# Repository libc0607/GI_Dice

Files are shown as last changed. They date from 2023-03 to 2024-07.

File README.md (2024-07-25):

本项目已停止更新，已停止任何形式的技术支持。但您仍然可以查看全部开源资料，并在遵守开源协议的情况下使用。  
如果您遇到任何问题，可以学习那位的美德后自行解决，也可以在教令院找阿帽。阿帽不好听吗？  

---

# GI Dice
这是一种原神七圣召唤中的元素骰子的可低成本 DIY 的实现  
本设计中，除了外壳、元素图标及 PCB 需要给 JLC 氪点之外，其余全部使用立创商城或淘宝零售可买到的全新部件实现，无需额外定制  
关于使用效果，你可以看看 [BV1Gs4y1t7k7](https://www.bilibili.com/video/BV1Gs4y1t7k7)  
  

## 特性
 - CH573F 主控，通过蓝牙广播实现多个骰子同时向中控传输骰子朝向及电量信息
 - 打牌计分中控我没打算做，但给出了在 ESP32-S3 上做接收的例程，想做中控的可以直接对接
 - LIS2DW12 三轴加速度传感器
 - 8 个 APA102 (SK9822) RGB LED，支持关断 LED 电源以省电（*见下文续航）
 - LIR1240 55mAh 锂电池，以及正经的充电管理和电池保护 IC
 - 使用无线充电，同样开源了配套的充电盒
 - 霍尔传感器实现放入充电盒后关断电源
 - 正八面体，边长 22mm

续航与电池电压、温度、元件及使用场景等多种因素有关，没有全面地测量过，这里只给出我的一次测量的结果用于粗略估计  
|  工作状态 | 电池的输出电流  |
|  ----  | ----  |
| 正常工作，蓝牙广播，1灯亮  | ~7.5mA |
| 正常工作，蓝牙配对，1灯亮  | ~9.5mA |
| 正常工作，蓝牙广播，灯灭  | ~2.5mA |
| 正常工作，蓝牙配对，灯灭  | ~4.5mA |
| 十分钟（默认）无动作后休眠  | ~数十uA |
| 放入充电盒盖上盖子  | ~8uA |

## TO-DOs 
写完各个 README 

## 开源协议  
本仓库内全部的 原理图、PCB、外壳，适用于 CERN-OHL-S v2 或任何之后的版本  
其中，霍尔开关和无线充电的部分设计有参考 [jeansimonet/Pixels](https://github.com/jeansimonet/Pixels) 项目，该项目基于 MIT 协议开源  
  
dice/src 下包含的软件中，我自己写的部分基于 GPL v3 开源（反正加一起也没写几行还写得那么烂不会真的有人想在这上面改吧x   
其他需要作出声明的包括：
 - lis2dw12 驱动来自 [STMicroelectronics/lis2dw12-pid](https://github.com/STMicroelectronics/lis2dw12-pid)，原代码基于 BSD 3-Clause 协议开源
 - 代码主体修改自 [CH573EVT](https://www.wch.cn/downloads/CH573EVT_ZIP.html) 的 BLE_UART 示例，原代码基于 Apache-2.0 协议开源  
 - esp32_dice_scanner 修改于 [espressif/arduino-esp32](https://github.com/espressif/arduino-esp32) 中提供的 BLE_Beacon_Scanner 示例，由于基于 LGPL-2.1 开源，这部分就跟着用相同的   

作者不对 dice/panel 目录下带有元素图标的面板打印文件声明任何协议，作者也没有把这个文件商用，总之就是先放这    
其中图纸来自 [B站 @芒果小强DY：教你如何实现元素骰子自由](https://www.bilibili.com/video/BV1S14y1K7hi)，但其中的美术素材（元素 Logo）版权归属于自由的 mhy  
如果认为这部分有侵权的话，请联系删除  

禁止拿去做毕设，你也不想被你的答辩老师知道你平日其实都在原神里打牌吧（

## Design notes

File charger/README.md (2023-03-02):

# 元素骰子用的无线充电器 
在 [这个视频](https://www.bilibili.com/video/BV1Gs4y1t7k7/) 中出现的充电器  
  
使用 XKT-511 方案，主要参考了 XKT511-21 这个验证板  
实测谐振频率 ~940kHz，接收侧使用 10uH 并联 2.2nF 即可  
在双路充电基础上增加了一个 CH552，用于检测充电电流、充电器内部温度和充电器的盖子状态   
不过这些功能的代码还全都没写，你可以先写两行把 XKT-511 的使能拉高，先用着。。  

硬件：双层板，板厚 1.6mm，白嫖即可，无特殊工艺要求  
除了两个 10nF 的谐振电容需要使用 C0G/NP0 材质外，其余均可参考原理图中元件型号  
建议用黑油，因为画得太丑了（悲  
  
配套的外壳见 stl/  
OSHWHub 的 PCB 工程链接：https://oshwhub.com/libc0607/gi_dice_charger_dual_nobat_v1_0_rel

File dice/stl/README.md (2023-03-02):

# 外壳
[一图流组装指南](https://github.com/libc0607/GI_Dice/blob/main/dice/stl/Schematic_gi_dice_doc_2023-03-02.pdf)

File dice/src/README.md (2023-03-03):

# BLE_Dice demo 

与 CH573EVT V2.2 版本一同测试通过  
代码参考了 CH573EVT V2.2 中的 BLE_UART Demo  
下文截图使用了沁恒的 BLE 调试助手 APP  

## 使用 BLE 和打牌中控进行交互  
如果你正试图实现打牌中控，那么目前支持通过两种方式经 BLE 获取骰子的状态信息，分别为监听广播包（一对多）和配对后（一对一）  


### 从广播包中获取信息   
  

| 长度 | 类型 | 数据 | 数据在 advert/scan_rsp 包中 | 备注 |
|---|---|---|---|---|
| 2 | GAP_ADTYPE_FLAGS | DEFAULT_DISCOVERABLE_MODE \| GAP_ADTYPE_FLAGS_BREDR_NOT_SUPPORTED | advert | 默认 | 
| 3 | GAP_ADTYPE_16BIT_MORE | 16bit 短 Service UUID，fff0 | advert | 修改自 BLE_UART，默认 |
| 5 | GAP_ADTYPE_MANUFACTURER_SPECIFIC | “制造商数据”：'G'(0x47), 'I'(0x49), (uint8)((电池电压mV-3200)/4), ([lis_dice_8d_t](https://github.com/libc0607/GI_Dice/blob/a4a67a805def9365946631231ff4620e6b9b3964/dice/src/BLE_Dice/APP/include/lis2dw12_glue.h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))朝向 | advert | 只解析这个即可 |
| 9 | GAP_ADTYPE_LOCAL_NAME_COMPLETE | 骰子显示的名称：Dice8AA1，前4固定，后4字节是MAC地址末尾且大写 | scan_rsp | 可用于判定&配对检查 | 
  
### BLE 配对后进行交互 
这部分本质上是直接使用了 BLE_UART 示例中提供的虚拟串口来发送与接收数据   
Service UUID 为 0xfff0  
  

Characteristic 0xfff1 为 骰子->中控，接收骰子发来的数据时，打开 Notify，然后接收就行   
数据格式为：
'#'，电池电压mV，温度（但是好像Bug了），([lis_dice_8d_t](https://github.com/libc0607/GI_Dice/blob/a4a67a805def9365946631231ff4620e6b9b3964/dice/src/BLE_Dice/APP/include/lis2dw12_glue.h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))朝向，加速度[0]，加速度[1]，加速度[2]  
其中加速度范围为 [-2000, 2000]，单位为 mg  
   

Characteristic 0xfff2 为 中控->骰子，这坨代码目前只能接收一种数据，即在接收到字符 'F' 后点亮全部 LED 约一秒，用于实现初次与中控配对时在一堆骰子里找到对应的骰子  


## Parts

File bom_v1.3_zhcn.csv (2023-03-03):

 |  | 部件 | 规格 | 数量 | 备注
骰子本体 电路部分 | PCB | GI_Dice_V1.3_Rel |  | 1 | JLC白嫖，https://oshwhub.com/libc0607/gi_dice_v1-3_rel
 | 元件 建议SMT | 100nF | C0402 | 6
 |  | 2.2uF | C0402 | 4
 |  | 10nF | C0402 | 2
 |  | 1uF | C0402 | 2 | 耐压25V或以上
 |  | 10uF | C0402 | 2
 |  | 100kΩ | R0402 | 2
 |  | 1MΩ | R0402 | 2
 |  | 1kΩ | R0402 | 1
 |  | 3.3kΩ | R0402 | 1
 |  | LIS2DW12TR | LGA-12_L2.0-W2.0-P0.50-BL | 1
 |  | LGS4056H | DFN-8_L2.0-W2.0-P0.50-BL-EP-1 | 1 | 有 4.2V 和 4.35V 版本，根据你的电池选择，通常选 4.2V
 |  | CM1124-EAC | DFN-4_L1.0-W1.0-P0.65-BL-EP-A | 1 | 有 4.2V 和 4.35V 版本，根据你的电池选择，通常选 4.2V
 | 元件 可以手焊 | CA-C01 2.4G天线 |  | 1 | https://item.taobao.com/item.htm?id=627328734225
 |  | 2.2nF | C0402 | 1 | 要 NP0/C0G 材质，耐压25V或以上，如 https://item.szlcsc.com/3443038.html
 |  | BAV99S | SOT-363_L2.1-W1.3-P0.65-LS2.3-BL | 1
 |  | 22uH | IND-SMD_L2.0-W1.6_NR201610 | 1 | 具体参考 CH573 手册，我实际用了个 10uH 0.4A 0603 功率电感 https://detail.tmall.com/item.htm?id=614042556481
 |  | APA102-2020 | APA102-2020 | 8 | https://item.taobao.com/item.htm?id=593679077814
 |  | TJ-S1615SW6TGLCRG-A5 | LED-ARRAY-SMD_4P-L1.6-W1.5-TR-RD_TJ-S1615SW6TGLCRB-A5 | 1 | 例如优信 https://item.taobao.com/item.htm?id=522572822666
 |  | CJE3139K | SC-75-3_L1.6-W0.8-P1.00-LS1.7-BR | 1
 |  | CH573F | QFN-28_L4.0-W4.0-P0.40-BL-EP2.8 | 1
 |  | SGM2036-3.3YC5G/TR | SC-70-5_L2.1-W1.3-P0.65-LS2.1-BR | 1
 |  | 8P FPC 排线 | 8P 0.8MM间距 30MM长 | 1 | https://item.taobao.com/item.htm?id=639292801110
 |  | 3P FPC 排线 | 3P 1.0MM间距 30MM长 | 1 | https://item.taobao.com/item.htm?id=639292801110
 |  | 74LVC1G00DCKR | SC-70-5_L2.0-W1.3-P0.65-LS2.1-BR | 1
 |  | HT7150S | SOT-23-3_L2.9-W1.5-P1.90-LS2.8-BR-CW | 1 | 可换，但注意输入耐压要高于25V
 |  | 32MHz | CRYSTAL-SMD_4P-L2.0-W1.6-BL-2 | 1
 |  | 32.768k | CRYSTAL-SMD_L2.1-W1.2-P1.50 | 0 | 仅预留，不用焊
 |  | CC6203ST? | SOT-23-3 | 1 | 也可换其他相似型号，https://item.szlcsc.com/271303.html
 |  | 10uH 电感 | CD53 | 2 | 磁路必须不能闭合，买最便宜的就对了；必须CD53，厚了塞不进去
 |  | 飞线 |  | 若干 | 可以买那种耳机用的线材，细一些
 |  | LIR1240 锂电池 | Φ 12mm*4mm | 1 | 淘宝很好买，如果担心盖不上，换薄一些的 301012 电池
骰子 结构组装 |  | 青稞纸 | 不要太厚的 | 若干 | 自己剪
 |  | 隔磁片 | 不要太厚的 | 若干 | 建议在给充电器买 XKT-511 时顺便一起买了
 |  | 双面胶 | 不要太厚的 | 若干
 |  | 10号订书钉 |  | 4 | 用于固定上下壳
 |  | 元素图标面板 | 透明亚克力/正面/0.8mm/常规遮光 | 8种元素，一套共8片 | 立创面板打印 https://github.com/libc0607/GI_Dice/blob/main/dice/panel/Panel_GI_Dice_Panel_Demo_2023-01-03.epanm
 |  | 外壳 | 光固化3D打印 | 2 | https://github.com/libc0607/GI_Dice/blob/main/dice/stl/dice_main_v1.3.STL
 |  | 金色喷漆 |  |  | 我用的三和35#，你可以选择更好的
 |  | 光油 |  |  | 我用的三和190#，你可以选择更好的
 |  | 磁铁 | Φ2mm * 1.5mm | 4（可选） | 用作上下壳间的定位柱，可选
 |  | 砂纸 |  | 若干
充电器 电路部分 |  | GI_Dice_Charger_V1.0_Rel |  | 1 | 可白嫖，https://oshwhub.com/libc0607/gi_dice_charger_dual_nobat_v1_0_rel
 |  | 10KΩ(1002) | R0603 | 1 | 热敏电阻，B3380
 |  | 5.1K | R0603 | 9
 |  | CC6201TO | TO-92S_3P-L4.1-W1.6-P1.27-L | 1 | https://item.szlcsc.com/271302.html
 |  | 10nF | C0603 | 2 | 要 NP0/C0G 材质，耐压不能太低，如 https://item.szlcsc.com/87149.html
 |  | 100nF | C0603 | 4
 |  | 22uF | C0805 | 2
 |  | Red | LED0603-R-RD | 1
 |  | Green | LED0603-R-RD | 1
 |  | 200kΩ | R0603 | 2
 |  | 11kΩ | R0603 | 2
 |  | 1MΩ | R0603 | 4
 |  | 100mΩ | R0805 | 2
 |  | XKT-511 | XKT-511 | 2 | https://item.taobao.com/item.htm?id=620604429073
 |  | CH552G | SOP-16_L10.0-W3.9-P1.27-LS6.0-BL | 1
 |  | SGM8522XS/TR | SOIC-8_L4.9-W3.9-P1.27-LS6.0-BL | 1 | 注意静电
 |  | TYPE-C-31-M-12 | USB-C_SMD-TYPE-C-31-M-12 | 1
充电器 外壳 |  | 外壳-本体 | 光固化3D打印 | 1 | https://github.com/libc0607/GI_Dice/blob/main/charger/stl/dualchrg-v1.0.STL
 |  | 外壳-底盖 | 光固化3D打印 | 1 | https://github.com/libc0607/GI_Dice/blob/main/charger/stl/dualchrg-bottom_v1.0.STL
 |  | 外壳-顶盖 | 光固化3D打印 | 1 | https://github.com/libc0607/GI_Dice/blob/main/charger/stl/dualchrg-cap_v1.2.STL
 |  | 磁铁 | Φ6mm * 0.5mm | 8 | 上下盖子磁吸用
 |  | 磁铁 | Φ8mm * 1.0mm | 2 | 关断骰子电源用
 |  | 磁铁 | Φ2mm * 1.5mm | 1 | 给合盖霍尔传感器用；上述所有磁铁可在同一店买到（*lalaci）
 |  | 砂纸 |  | 若干

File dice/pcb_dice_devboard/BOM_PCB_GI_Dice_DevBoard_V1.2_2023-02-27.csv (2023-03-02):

ID | Name | Designator | Footprint | Quantity | Manufacturer Part | Manufacturer | Supplier | Supplier Part | Price
1 | C23630 | C4 | C0603 | 1 | C2980295 | SAMSUNG(三星) | LCSC | C23630 | 0.0336
2 | 100nF | C2,C8,C12,C13 | C0603 | 4 | CC0603KRX7R9BB104 | YAGEO(国巨) | LCSC | C14663 | 0.0149
3 | 2.2uF | C3,C5,C6,C7,C14,C15 | C0603 | 6 | CL10A225KO8NNNC | SAMSUNG(三星) | LCSC | C23630 | 0.0336
4 | C23630 | C1 | C0603 | 1 | CC0603KRX7R9BB104 | YAGEO(国巨) | LCSC | C14663 | 0.0149
5 | 10uF | C10,C11 | C0603 | 2 | CL10A106KP8NNNC | SAMSUNG(三星) | LCSC | C19702 | 0.0417
6 | 2.2nF | C9 | C0402 | 1 | 0402B222K500NT | FH(风华) | LCSC | C1531 | 0.0063
7 | BAV99S | D2 | SOT-363_L2.1-W1.3-P0.65-LS2.3-BL | 1 | BAV99S | CJ(江苏长电/长晶) | LCSC | C68987 | 0.3179
8 | Z-211-0511-0021-001 | H1 | HDR-TH_5P-P2.54-V_Z-211-0511-0021-001 | 1 | Z-21105110021001 | Nextron(正凌) | LCSC | C188243 | 0.1983
9 | 22uH | L1 | IND-SMD_L2.0-W1.6_NR201610 | 1 | YNR2016-220M | YJYCOIN(益嘉源) | LCSC | C2858408 | 0.3743
10 | OA-C07 | L4 | OA-C07 | 1
11 | APA102-2020 | LED1,LED2,LED3,LED4,LED5,LED6,LED7,LED9 | APA102-2020-COPY | 8 | APA102-2020 |  | LCSC | C9900001305
12 | 19-217/GHC-YR1S2/3T | LED8 | LED0603-R-RD | 1 | 19-217/GHC-YR1S2/3T | EVERLIGHT(亿光) | LCSC | C72043 | 0.1678
13 | KT-0603R | LED10 | LED0603-R-RD | 1 | KT-0603R | null | LCSC | C2286 | 0.0332
14 | 100kΩ | R1 | R0603 | 1 | 0603WAF1003T5E | UNI-ROYAL(厚声) | LCSC | C25803 | 0.0068
15 | 1MΩ | R2,R5 | R0603 | 2 | 0603WAF1004T5E | UNI-ROYAL(厚声) | LCSC | C22935 | 0.0059
16 | 15kΩ | R3,R4,R6 | R0603 | 3 | 0603WAF1502T5E | UNI-ROYAL(厚声) | LCSC | C22809 | 0.0065
17 | 5.1kΩ | R7,R8 | R0603 | 2 | 0603WAF5101T5E | UNI-ROYAL(厚声) | LCSC | C23186 | 0.0061
18 | TS-1088-AR02016 | SW1 | SW-SMD_L3.9-W3.0-P4.45 | 1 | TS-1088-AR02016 | XUNPU(讯普) | LCSC | C720477 | 0.2947
19 | LIS2DW12TR | U1 | LGA-12_L2.0-W2.0-P0.50-BL | 1 | LIS2DW12TR | ST(意法半导体) | LCSC | C189624 | 5.28
20 | CH582F | U2 | QFN-28_L4.0-W4.0-P0.40-BL-EP2.8 | 1 | CH582F | WCH(南京沁恒) | LCSC | C3001175 | 6.79
21 | LP5907MFX-3.3/NOPB | U3 | SOT-23-5_L3.0-W1.7-P0.95-LS2.8-BR | 1 | LP5907MFX-3.3/NOPB | TI(德州仪器) | LCSC | C80670 | 1.676
22 | SY6280AAC | U4 | SOT-23-5_L3.0-W1.7-P0.95-LS2.8-BR | 1 | SY6280AAC | 矽力杰silergy | LCSC | C55136 | 1.0866
23 | TP4057 | U6 | SOT-23-6_L2.9-W1.6-P0.95-LS2.8-BR | 1 | TP4057-42-SOT26-R | TOPPOWER(南京拓微) | LCSC | C12044 | 0.8511
24 | CC6201ST | U7 | SOT-23-3_L2.9-W1.3-P1.90-LS2.4-BR | 1 | CC6201ST | CrossChip(成都芯进) | LCSC | C285995 | 0.6216
25 | 74LVC1G08 | U10 | SC-70-5_L2.0-W1.3-P0.65-LS2.1-BR | 1 | SN74LVC1G08DCKR | UMW(友台半导体) | LCSC | C2983745 | 0.3563
26 | HT7550S | U11 | SOT-23-3_L2.9-W1.5-P1.90-LS2.8-BR-CW | 1 | HT7550S | UMW(友台半导体) | LCSC | C347217 | 0.3053
27 | TYPE-C-31-M-12 | USBC2 | USB-C_SMD-TYPE-C-31-M-12 | 1 | TYPE-C-31-M-12 | Rectangular Connectors - Contacts | LCSC | C165948 | 1.3658
28 | 32MHz | X1 | CRYSTAL-SMD_4P-L2.0-W1.6-BL-2 | 1 | X201632MOB4SI | YXC(扬兴晶振) | LCSC | C2682773 | 0.6645
29 | 32.768k | X2 | CRYSTAL-SMD_L2.1-W1.2-P1.50 | 1 | TJXM32768K2TGDCNT2T | TAE(Zhejiang Abel Elec) | LCSC | C403709 | 1.637
30 | 22-28-4020 | CN1,CN2 | HDR-TH_2P-P2.54-V-M-1 | 2 | 22284020 | MOLEX | LCSC | C234182 | 0.5255

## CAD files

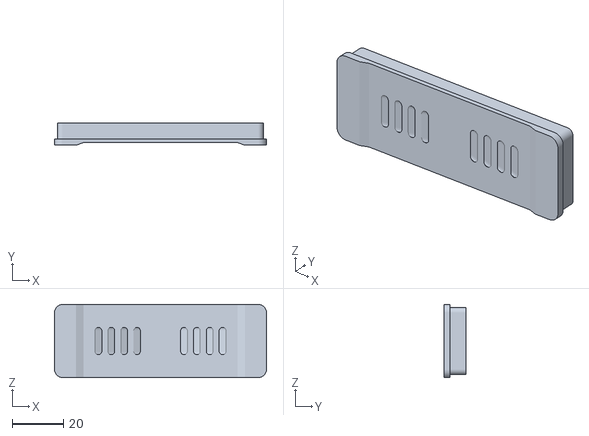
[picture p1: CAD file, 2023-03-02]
charger/stl/dualchrg-bottom_v1.0.STL
82.4 x 8.70 x 28.4

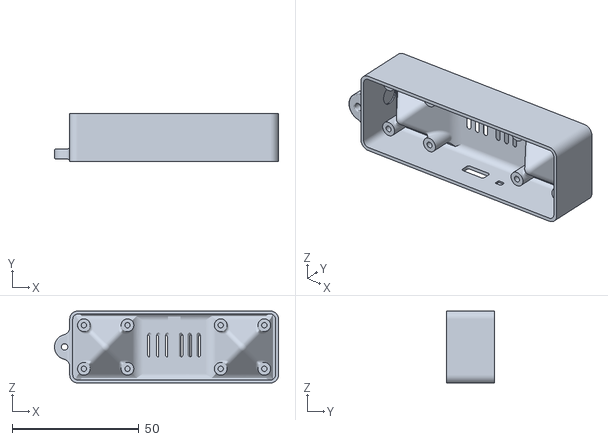
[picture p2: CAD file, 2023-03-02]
charger/stl/dualchrg-v1.0.STL
88.4 x 19.0 x 28.4

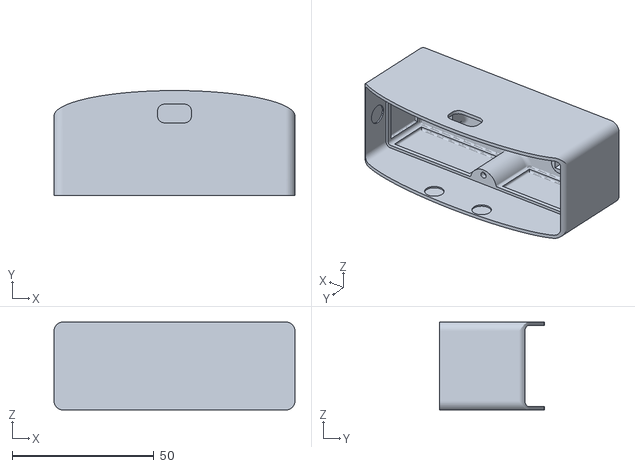
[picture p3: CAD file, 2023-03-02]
charger/stl/dualchrg-cap_v1.2.STL
85.0 x 37.0 x 31.0

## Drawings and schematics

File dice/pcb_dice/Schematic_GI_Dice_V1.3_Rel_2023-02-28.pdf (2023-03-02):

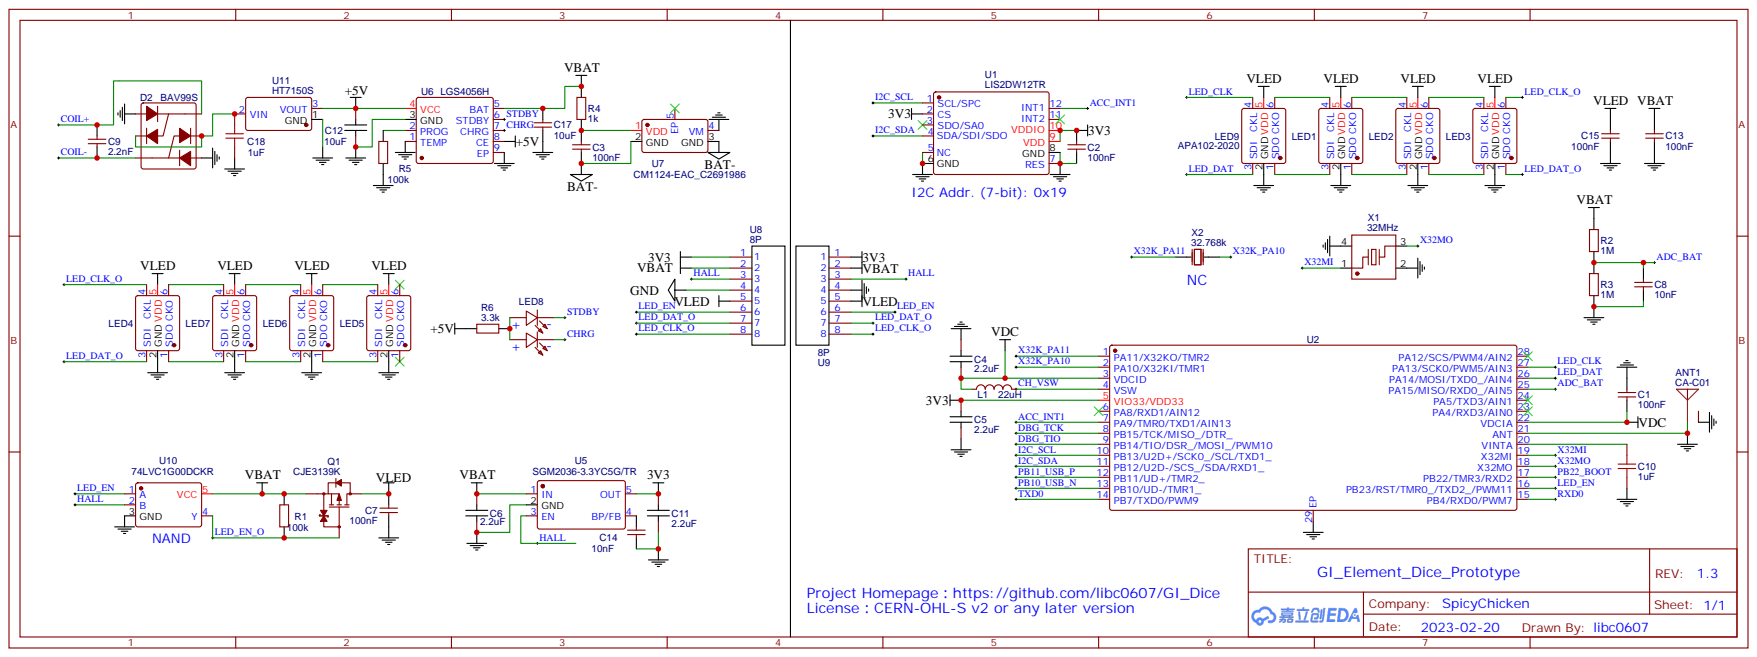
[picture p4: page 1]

Project Homepage：https://github.com/libc0607/GI_Dice
License：CERN-OHL-S v2 or any later version

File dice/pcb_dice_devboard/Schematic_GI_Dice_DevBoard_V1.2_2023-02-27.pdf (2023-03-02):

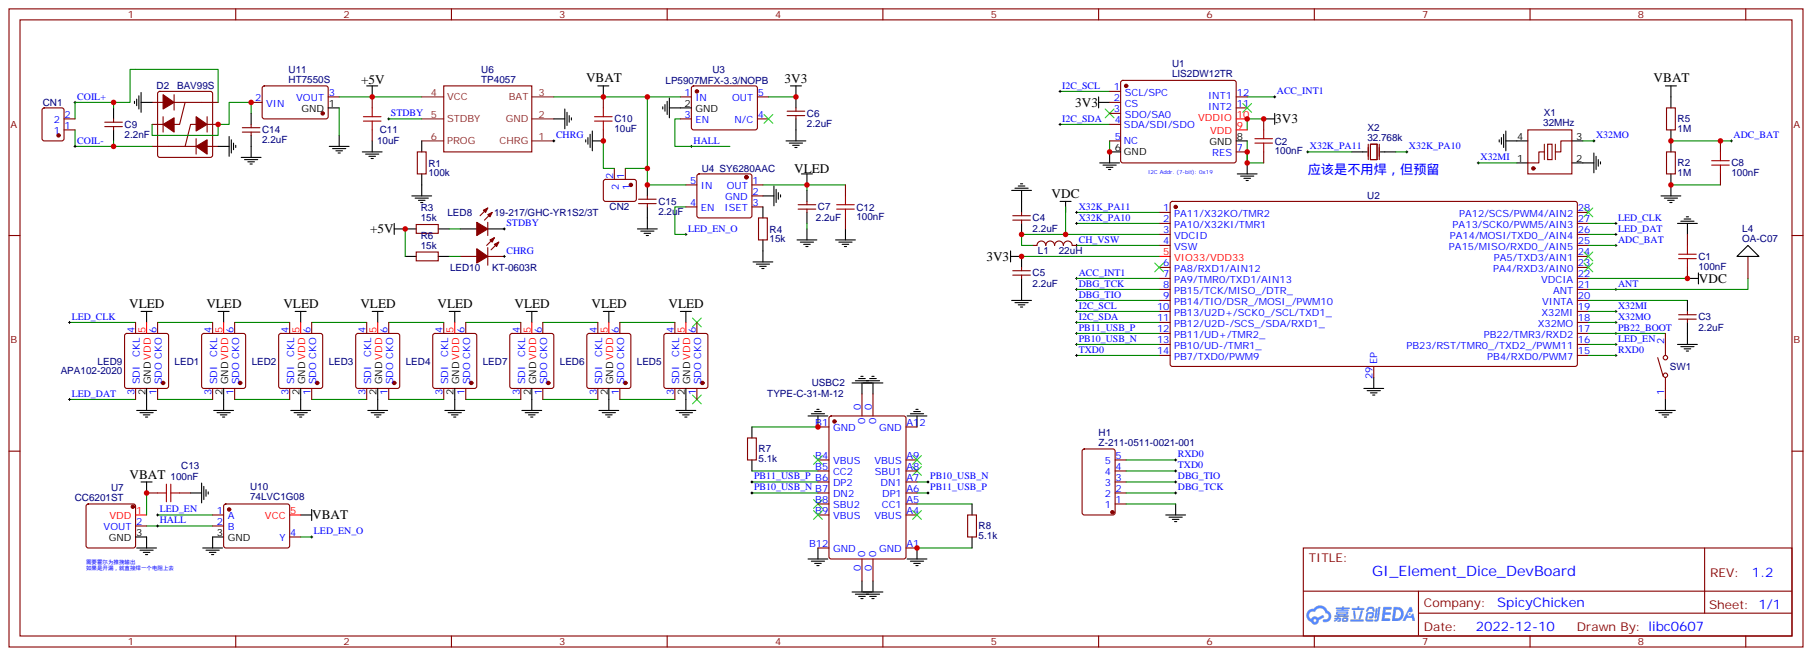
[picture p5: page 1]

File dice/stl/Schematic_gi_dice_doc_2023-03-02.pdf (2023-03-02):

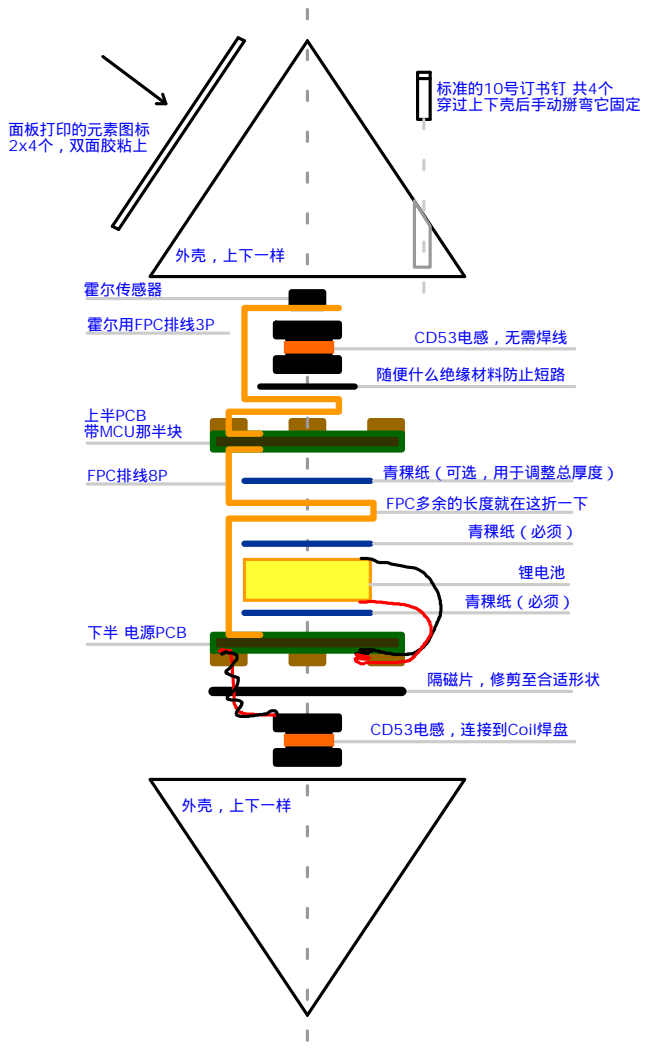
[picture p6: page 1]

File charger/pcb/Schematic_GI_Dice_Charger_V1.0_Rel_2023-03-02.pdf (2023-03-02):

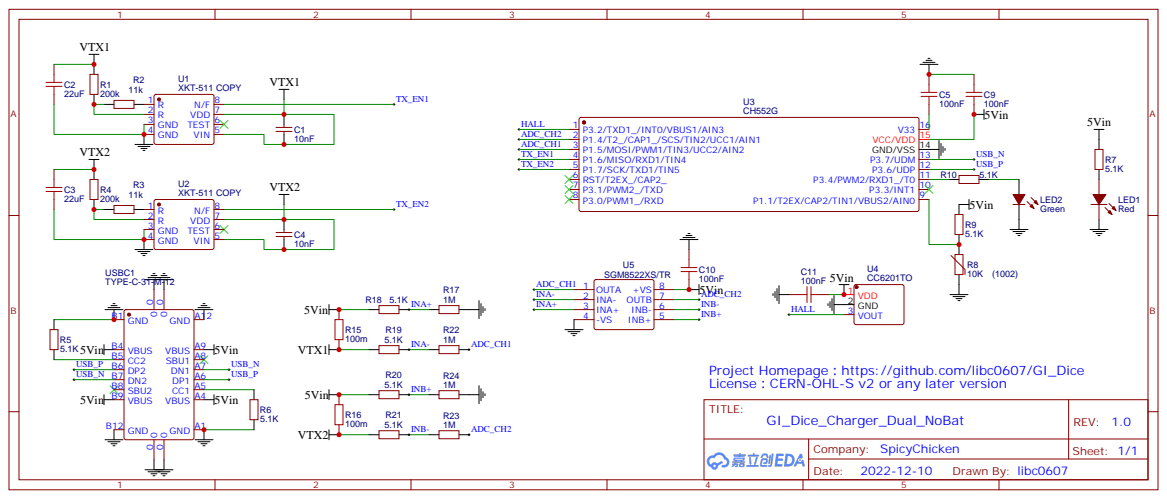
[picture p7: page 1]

Project Homepage：https://github.com/libc0607/GI_Dice
License：CERN-OHL-S v2 or any later version

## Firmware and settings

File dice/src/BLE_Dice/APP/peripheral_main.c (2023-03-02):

/*
 * Genshin Impact Genius Invokation Element Dice
 *
 * HW Version: V1.2
 * Github: https://github.com/libc0607/GI_Dice
 *
 * Ref: CH573EVT V2.2, BLE_UART demo
 */

#include "CONFIG.h"
#include "HAL.h"
#include "gattprofile.h"
#include "peripheral.h"
#include "dice_misc.h"
#include "lis2dw12_glue.h"
#include "apa102.h"

__attribute__((aligned(4))) u32 MEM_BUF[BLE_MEMHEAP_SIZE / 4];
extern void app_uart_init(void);

__attribute__((section(".highcode")))
__attribute__((noinline))
void Main_Circulation()
{
    while(1)
        TMOS_SystemProcess();
}

/*
__attribute__((interrupt("WCH-Interrupt-fast")))
__attribute__((section(".highcode")))
void GPIOA_IRQHandler(void)
{
    GPIOA_ClearITFlagBit(PIN_ACC_INT);
}
*/

int main(void)
{
    int bat_mv;
    uint32_t color_bat;

    PWR_DCDCCfg(ENABLE);
    SetSysClock(FREQ_SOURCE);

    pin_init();
    UART0_DefInit();
    PRINT("%s\n", VER_LIB);
    acc_init();
    apa102_spi0_init();
    apa102_power_enable(TRUE);

    // blinky battery indicator
    bat_mv = get_battery_voltage_mv();
    color_bat = get_led_color_by_battery(bat_mv);
    apa102_turn_off_all(); apa102_set_color_all(LED_STAT_BRIGHTNESS_DEFAULT, color_bat); apa102_update(); DelayMs(BOOT_BLINK_INTERVAL);
    apa102_turn_off_all(); apa102_update(); DelayMs(BOOT_BLINK_INTERVAL);
    apa102_turn_off_all(); apa102_set_color_all(LED_STAT_BRIGHTNESS_DEFAULT, color_bat); apa102_update(); DelayMs(BOOT_BLINK_INTERVAL);
    apa102_turn_off_all(); apa102_update(); DelayMs(BOOT_BLINK_INTERVAL);
    apa102_turn_off_all(); apa102_set_color_all(LED_STAT_BRIGHTNESS_DEFAULT, color_bat); apa102_update(); DelayMs(BOOT_BLINK_INTERVAL);
    apa102_turn_off_all(); apa102_update();
    apa102_power_enable(FALSE);

    if (bat_mv < BAT_HALT_MV) {
        acc_low_power();
        DelayMs(1);
        pin_init_sleep();
        DelayMs(2);
        LowPower_Shutdown(0);
    }

    CH57X_BLEInit();
    HAL_Init();
    GAPRole_PeripheralInit();
    Peripheral_Init();
    app_uart_init();
    dice_process_init();

    Main_Circulation();
}

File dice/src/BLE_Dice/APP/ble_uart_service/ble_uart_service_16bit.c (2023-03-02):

/********************************** (C) COPYRIGHT *******************************
 * File Name          : ble_uart_service_16bit_char.c
 * Author             : WCH
 * Version            : V1.1
 * Date               : 2022/01/19
 * Description        :
 * Copyright (c) 2021 Nanjing Qinheng Microelectronics Co., Ltd.
 * SPDX-License-Identifier: Apache-2.0
 *******************************************************************************/

/*********************************************************************
 * INCLUDES
 */

#include "CONFIG.h"
#include "gattprofile.h"
#include "stdint.h"
#include "ble_uart_service.h"


/*********************************************************************
 * MACROS
 */

/*********************************************************************
 * CONSTANTS
 */

#define SERVAPP_NUM_ATTR_SUPPORTED    7

#define RAWPASS_TX_VALUE_HANDLE       2
#define RAWPASS_RX_VALUE_HANDLE       5
/*********************************************************************
 * TYPEDEFS
 */

/*********************************************************************
 * GLOBAL VARIABLES
 */

// ble_uart GATT Profile Service UUID
const uint8_t ble_uart_ServiceUUID[ATT_BT_UUID_SIZE] =
    {BLE_UART_SERVICE_UUID_LO, BLE_UART_SERVICE_UUID_HI};

// Characteristic rx uuid
const uint8_t ble_uart_RxCharUUID[ATT_BT_UUID_SIZE] =
    {BLE_UART_CHAR_RX_UUID_LO, BLE_UART_CHAR_RX_UUID_HI};

// Characteristic tx uuid
const uint8_t ble_uart_TxCharUUID[ATT_BT_UUID_SIZE] =
    {BLE_UART_CHAR_TX_UUID_LO, BLE_UART_CHAR_TX_UUID_HI};

/*********************************************************************
 * EXTERNAL VARIABLES
 */

/*********************************************************************
 * EXTERNAL FUNCTIONS
 */

/*********************************************************************
 * LOCAL VARIABLES
 */

static ble_uart_ProfileChangeCB_t ble_uart_AppCBs = NULL;

/*********************************************************************
 * Profile Attributes - variables
 */

// Profile Service attribute
static const gattAttrType_t ble_uart_Service = {ATT_BT_UUID_SIZE, ble_uart_ServiceUUID};

// Profile Characteristic 1 Properties
//static uint8 ble_uart_RxCharProps = GATT_PROP_WRITE_NO_RSP| GATT_PROP_WRITE;
static uint8 ble_uart_RxCharProps = GATT_PROP_WRITE_NO_RSP | GATT_PROP_WRITE;

// Characteristic 1 Value
static uint8 ble_uart_RxCharValue[BLE_UART_RX_BUFF_SIZE];
//static uint8 ble_uart_RxCharValue[1];

// Profile Characteristic 2 Properties
//static uint8 ble_uart_TxCharProps = GATT_PROP_NOTIFY| GATT_PROP_INDICATE;
static uint8 ble_uart_TxCharProps = GATT_PROP_NOTIFY;

// Characteristic 2 Value
static uint8 ble_uart_TxCharValue = 0;

// Simple Profile Characteristic 2 User Description
static gattCharCfg_t ble_uart_TxCCCD[4];

/*********************************************************************
 * Profile Attributes - Table
 */

static gattAttribute_t ble_uart_ProfileAttrTbl[] = {
    // Simple Profile Service
    {
        {ATT_BT_UUID_SIZE, primaryServiceUUID}, /* type */
        GATT_PERMIT_READ,                       /* permissions */
        0,                                      /* handle */
        (uint8 *)&ble_uart_Service              /* pValue */
    },

    // Characteristic 2 Declaration
    {
        {ATT_BT_UUID_SIZE, characterUUID},
        GATT_PERMIT_READ,
        0,
        &ble_uart_TxCharProps},

    // Characteristic Value 2
    {
        {ATT_BT_UUID_SIZE, ble_uart_TxCharUUID},
        0,
        0,
        (uint8 *)&ble_uart_TxCharValue},

    // Characteristic 2 User Description
    {
        {ATT_BT_UUID_SIZE, clientCharCfgUUID},
        GATT_PERMIT_READ | GATT_PERMIT_WRITE,
        0,
        (uint8 *)ble_uart_TxCCCD},

    // Characteristic 1 Declaration
    {
        {ATT_BT_UUID_SIZE, characterUUID},
        GATT_PERMIT_READ,
        0,
        &ble_uart_RxCharProps},

    // Characteristic Value 1
    {
        {ATT_BT_UUID_SIZE, ble_uart_RxCharUUID},
        GATT_PERMIT_WRITE,
        0,
        &ble_uart_RxCharValue[0]},

};

/*********************************************************************
 * LOCAL FUNCTIONS
 */
static bStatus_t ble_uart_ReadAttrCB(uint16 connHandle, gattAttribute_t *pAttr,
                                     uint8 *pValue, uint16 *pLen, uint16 offset, uint16 maxLen, uint8 method);
static bStatus_t ble_uart_WriteAttrCB(uint16 connHandle, gattAttribute_t *pAttr,
                                      uint8 *pValue, uint16 len, uint16 offset, uint8 method);

static void ble_uart_HandleConnStatusCB(uint16 connHandle, uint8 changeType);

/*********************************************************************
 * PROFILE CALLBACKS
 */
// Simple Profile Service Callbacks
gattServiceCBs_t ble_uart_ProfileCBs = {
    ble_uart_ReadAttrCB,  // Read callback function pointer
    ble_uart_WriteAttrCB, // Write callback function pointer
    NULL                  // Authorization callback function pointer
};

/*********************************************************************
 * PUBLIC FUNCTIONS
 */

/*********************************************************************
 * @fn      ble_uart_AddService
 *
 * @brief   Initializes the Simple Profile service by registering
 *          GATT attributes with the GATT server.
 *
 * @param   services - services to add. This is a bit map and can
 *                     contain more than one service.
 *
 * @return  Success or Failure
 */
bStatus_t ble_uart_add_service(ble_uart_ProfileChangeCB_t cb)
{
    uint8 status = SUCCESS;

    GATTServApp_InitCharCfg(INVALID_CONNHANDLE, ble_uart_TxCCCD);
    // Register with Link DB to receive link status change callback
    linkDB_Register(ble_uart_HandleConnStatusCB);

    //    ble_uart_TxCCCD.connHandle = INVALID_CONNHANDLE;
    //    ble_uart_TxCCCD.value = 0;
    // Register GATT attribute list and CBs with GATT Server App
    status = GATTServApp_RegisterService(ble_uart_ProfileAttrTbl,
                                         GATT_NUM_ATTRS(ble_uart_ProfileAttrTbl),
                                         GATT_MAX_ENCRYPT_KEY_SIZE,
                                         &ble_uart_ProfileCBs);
    if(status != SUCCESS)
        PRINT("Add ble uart service failed!\n");
    ble_uart_AppCBs = cb;

    return (status);
}
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
